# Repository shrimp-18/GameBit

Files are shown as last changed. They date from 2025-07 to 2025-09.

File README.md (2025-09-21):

# GameBit
GameBit is a custom project made for Hackclub. 
It is a portable Gaming Console (HAT) with a 2 inch LCD Screen, Audio Capabilities, 8 buttons for gameplay and 2 for on/off functionality, powered by a Raspberry Pi Zero 2W.
It is 130 X 44 mm in dimensions. 

I plan to put custom games in it :3
I made GameBit because I've always wanted to build a hardware project on my own and making a gaming console seemed cute. It was a very challenging project for a beginner, but I have learned a lot in the journey of making it. Game consoles are something that exist and I found a couple tutorials here and there but i still had to use a lot of my own brain to make it. But the experience I got from making this one will help me make a project I've been wanting to make since years and the tutorials for which do not exist.
3D View:


The Schematic:


The PCB:


The BOM:


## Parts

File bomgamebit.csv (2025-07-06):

Reference | Value | Datasheet | Footprint | Qty | DNP | Part
C1 | 0.1uF | https://lcsc.com/datasheet/lcsc_datasheet_2304140030_TORCH-CT41G-0805-2X1-50V-0-1-F-M-N_C138340.pdf | cap:C_0805 | 1 |  | 0.1uF Capacitor
C2 | 10uF | https://lcsc.com/datasheet/lcsc_datasheet_2304140030_Samsung-Electro-Mechanics-CL21A106KAYNNNE_C15850.pdf | cap:C_0805 | 1 |  | 10uF Capacitor
J1 | Conn_01x08_MountingPin | https://lcsc.com/product-detail/image/HB-PH3-25418PB2GOP_C6332201.html | mount:HB_PH3_25418PB2GOP_8Pin | 1 |  | Mounting pin 1x8
J3 | Conn_01x02 | https://lcsc.com/product-detail/image/PZ254V-11-02P_C492401.html | cap:PZ254V_11_02P | 1 |  | Mounting pin 1x2
LS1 | Speaker | https://jlcpcb.com/api/file/downloadByFileSystemAccessId/8590165296179802112 |  | 1 | DNP | Speaker 8ohm
SW1,SW2,SW3,SW4,SW5,SW6,SW7,SW8 | SW_Push | https://www.khon-switch.com/upload/1c/202404/TSW08131.pdf | button8:TSX08131_3.4x3.0_SMT | 8 |  | 8X8 tactile push button
SW9 | SW_SHDN | https://www.khon-switch.com/upload/1c/202404/TSW08131.pdf | on/off:TSX08131_3.4x3.0_SMT | 1 |  | 8X8 tactile push button
SW10 | JS102011SAQN | https://lcsc.com/datasheet/lcsc_datasheet_2410010333_C-K-JS102011SAQN_C221660.pdf | on/off:CK_JS102011SAQN | 1 |  | Slide button
U1 | SC1176 | https://datasheets.raspberrypi.com/rpizero2/raspberry-pi-zero-2-w-product-brief.pdf | rpi:MODULE_SC1176 | 1 |  | Raspberry Pi Zero 2W
U2 | MAX98357A | https://www.analog.com/media/en/technical-documentation/data-sheets/MAX98357A-MAX98357B.pdf | Package_DFN_QFN:TQFN-16-1EP_3x3mm_P0.5mm_EP1.23x1.23mm | 1 |  | Audio Module
LCD |  | https://files.waveshare.com/upload/a/ad/ST7789VW.pdf |  | 1 | DNP | LCD Display

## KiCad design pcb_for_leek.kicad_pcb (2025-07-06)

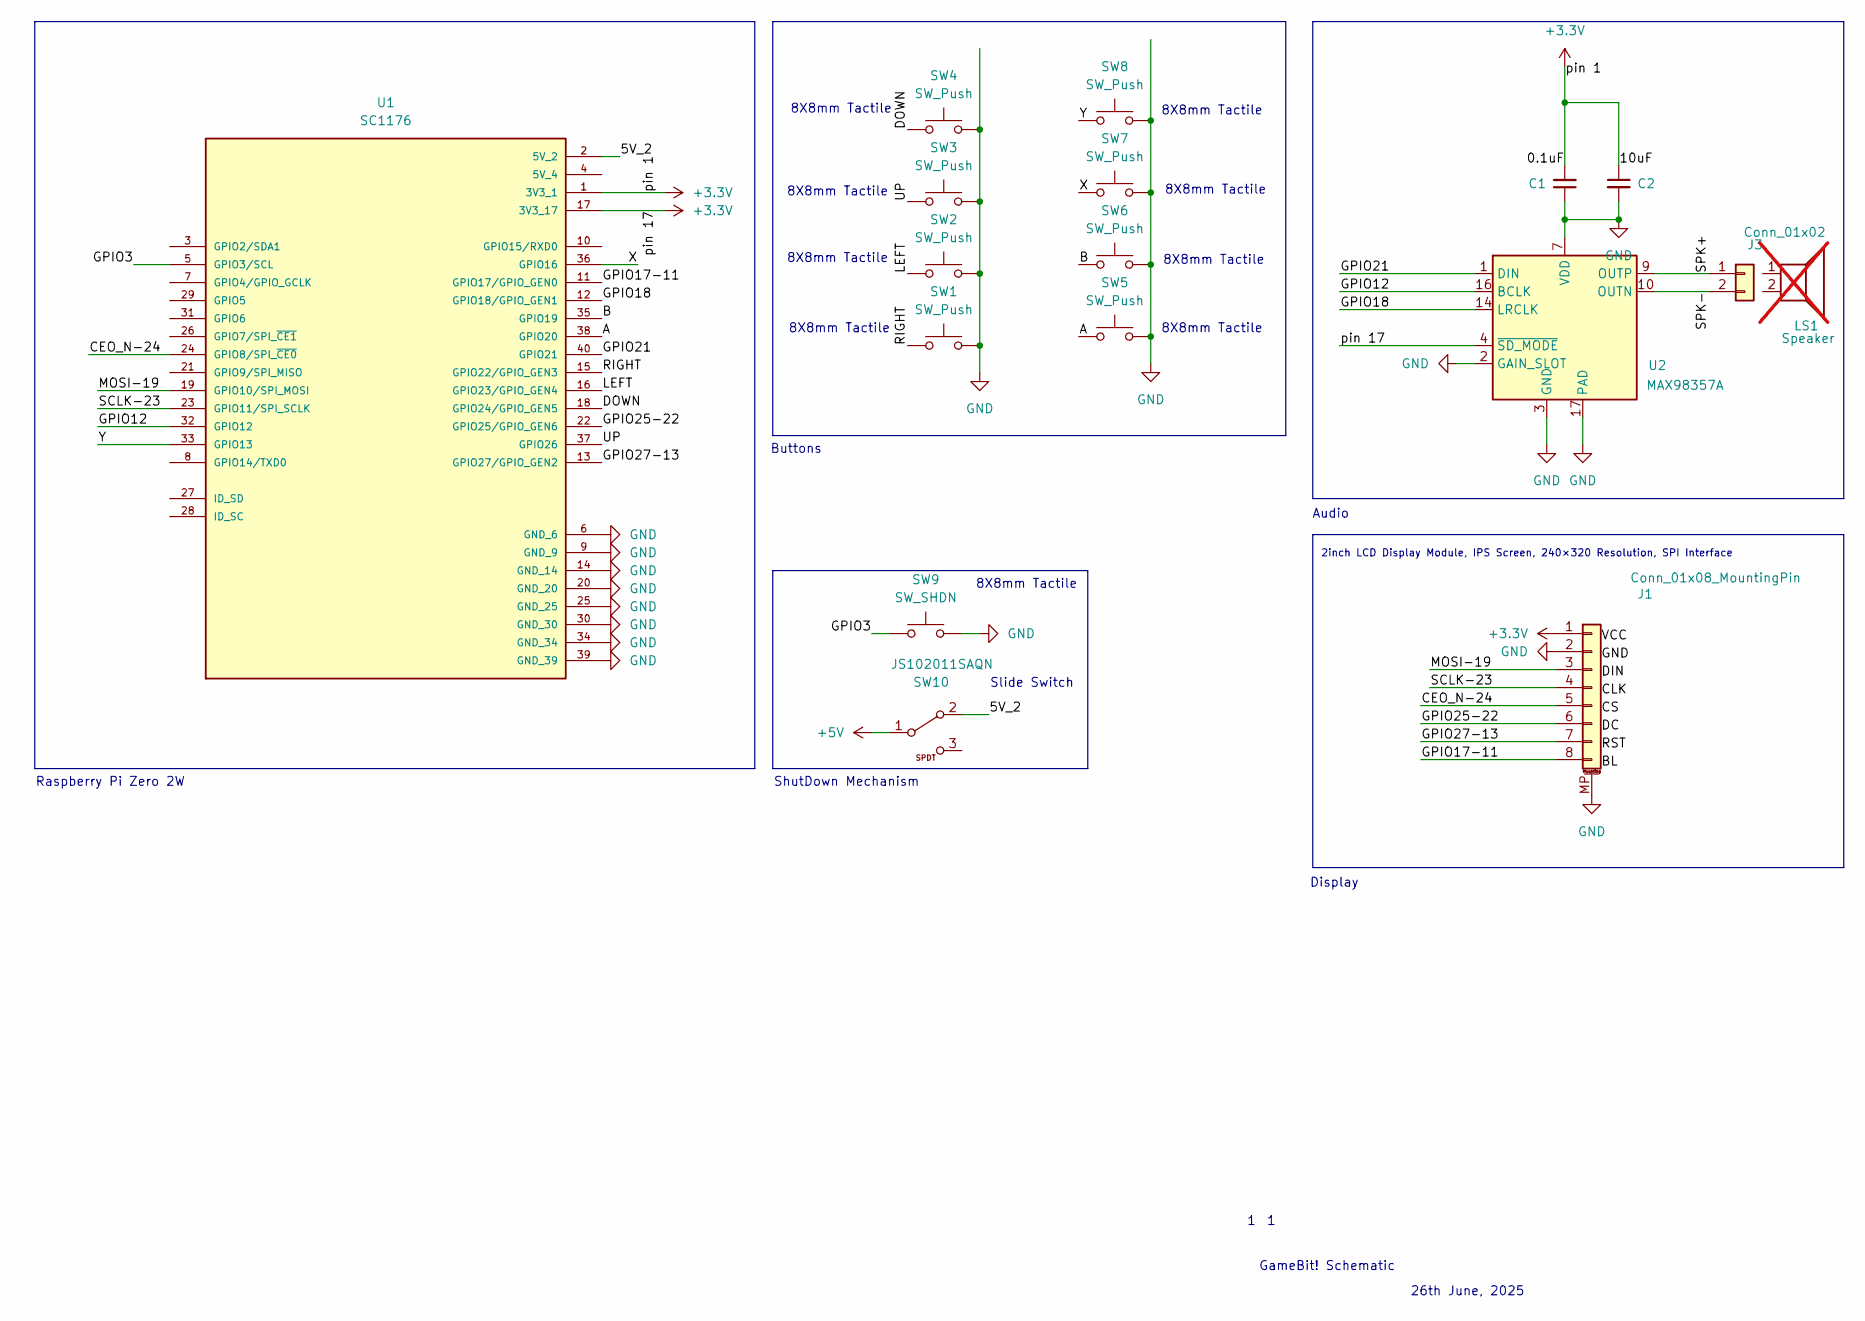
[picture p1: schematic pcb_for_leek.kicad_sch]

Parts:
C1: 0.1uF; C_0805
C2: 10uF; C_0805
J1: Conn_01x08_MountingPin; HB_PH3_25418PB2GOP_8Pin
J3: Conn_01x02; PZ254V_11_02P
LS1: Speaker; not fitted
SW1, SW2, SW3, SW4, SW5, SW6, SW7, SW8: SW_Push; TSX08131_3.4x3.0_SMT
SW9: SW_SHDN; TSX08131_3.4x3.0_SMT
SW10: JS102011SAQN; CK_JS102011SAQN; MPN JS102011SAQN; LCSC C221660
U1: SC1176; MODULE_SC1176; PARTREV April 2024; DigiKey_Part_Number 2648-SC1176-ND
U2: MAX98357A; TQFN-16-1EP_3x3mm_P0.5mm_EP1.23x1.23mm

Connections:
+3.3V: C1.2, C2.1, J1.1, U1.1 (3V3_1), U1.17 (3V3_17), U2.4 (~SD_MODE)
+5V: SW10.1 (COM)
/5V_2: SW10.2 (NO), U1.2 (5V_2)
/A: SW5.1, U1.38 (GPIO20)
/B: SW6.1, U1.35 (GPIO19)
/CEO_N-24: J1.5, U1.24 (GPIO8/SPI_~CE0)
/DOWN: SW4.1, U1.18 (GPIO24/GPIO_GEN5)
/GPIO3: SW9.1, U1.5 (GPIO3/SCL)
/GPIO12: U1.32 (GPIO12), U2.16 (BCLK)
/GPIO17-11: J1.8, U1.11 (GPIO17/GPIO_GEN0)
/GPIO18: U1.12 (GPIO18/GPIO_GEN1), U2.14 (LRCLK)
/GPIO21: U1.40 (GPIO21), U2.1 (DIN)
/GPIO25-22: J1.6, U1.22 (GPIO25/GPIO_GEN6)
/GPIO27-13: J1.7, U1.13 (GPIO27/GPIO_GEN2)
/LEFT: SW2.1, U1.16 (GPIO23/GPIO_GEN4)
/MOSI-19: J1.3, U1.19 (GPIO10/SPI_MOSI)
/RIGHT: SW1.1, U1.15 (GPIO22/GPIO_GEN3)
/SCLK-23: J1.4, U1.23 (GPIO11/SPI_SCLK)
/SPK+: J3.1 (SPK+), U2.9 (OUTP)
/SPK-: J3.2 (SPK-), U2.10 (OUTN)
/UP: SW3.1, U1.37 (GPIO26)
/X: SW7.1, U1.36 (GPIO16)
/Y: SW8.1, U1.33 (GPIO13)
GND: C1.1, C2.2, J1.2, J1.MP (MountPin), SW1.2, SW2.2, SW3.2, SW4.2, SW5.2, SW6.2, SW7.2, SW8.2, SW9.2, U1.6 (GND_6), U1.9 (GND_9), U1.14 (GND_14), U1.20 (GND_20), U1.25 (GND_25), U1.30 (GND_30), U1.34 (GND_34), U1.39 (GND_39), U2.2 (GAIN_SLOT), U2.3 (GND), U2.7 (VDD), U2.8 (VDD), U2.11 (GND), U2.15 (GND), U2.17 (PAD)

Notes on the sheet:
8X8mm Tactile
Audio
2inch LCD Display Module, IPS Screen, 240×320 Resolution, SPI Interface
GameBit! Schematic
26th June, 2025
Slide Switch
Raspberry Pi Zero 2W
Display
Buttons
ShutDown Mechanism

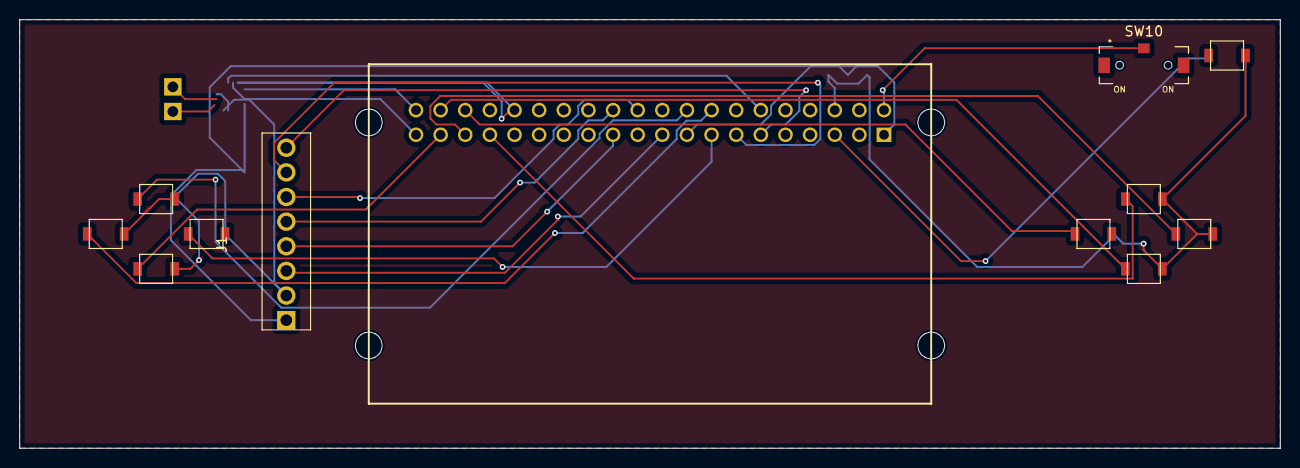
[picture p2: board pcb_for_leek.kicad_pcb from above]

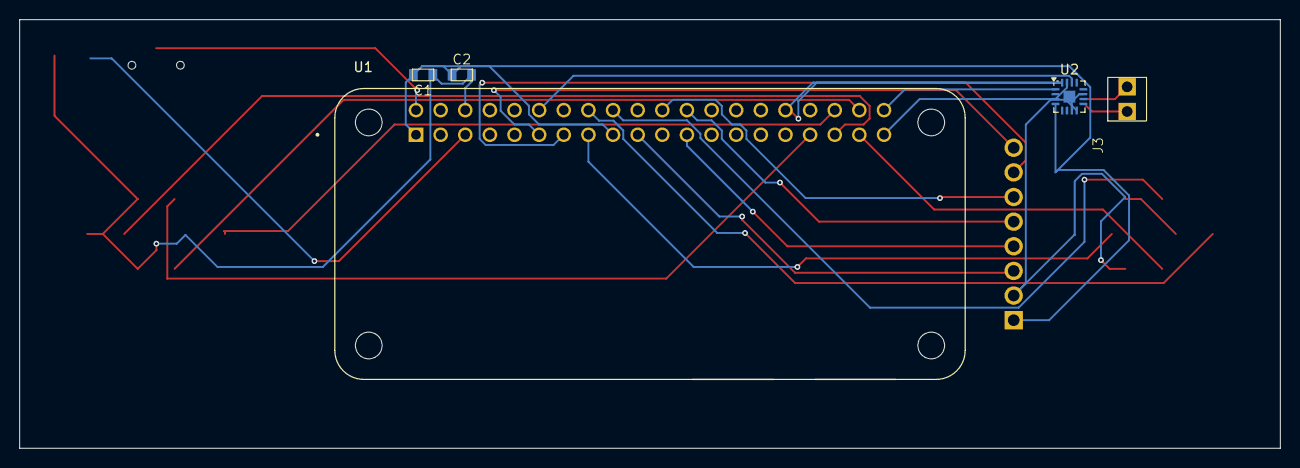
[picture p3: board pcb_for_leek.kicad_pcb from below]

Board: 2 copper layers, 130.0 x 44.2 mm, 16 parts (5 on the bottom side), 23 nets.

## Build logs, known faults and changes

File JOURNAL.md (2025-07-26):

---
Title: GameBit! Game Controller
Author: Neha A.
Description: A cuter and better GameBoy micro
Created_At: 24th June,2025
---
Total Time: 27 hours

(I didn't journal v actively as I was building this game console, so a lot of it is taken from my friend's DMs whom i regularly updated and my ChatGPT history)

10th May, 2025
The day I first started pondering the idea, I researched existing game consoles like the Hackapet, Sprig, and Pi-tin console etc.
Also saw a hell lot of yt tutorials on how game consoles are made, and also how to use kicad...bcs this is my second hardware project 
first was hackercard on easyeda.
Session: 3 hours (4pm to 7pm)

11th May, 2025
I decided to make something like the Game Boy Micro. Browsed a lot on LCSC, JLCPCB, and Waveshare on what hardware components to use.
For the mcu i settled on rpi 02W. Also found a good 2 inch lcd display on waveshare. Set up my kicad.
Session: 3 hours (8pm-11pm)

15th May,2025
In my schematic i made a system for the rpi to send data and power through a usb c cable which i thought would be useful (in the later stages i eventually remove it)
Also turns out that the connections i made were probably wrong.

Session : 2hours


25th May, 2025
By this time i realised by sending stuff on #electronics and smart hardware ppl that the usb c thingy wasnt really gonna work.So after more browsing and talking to chatgpt i settled on this chatgpt response. I figured I could just use the cable that the rpi  usually uses, and for portability I could use an <expensive> rechargable battery pack.
I also realised that the kicad symbol for the rpi i had been using all along were WRONG. So i found the correct symbol and footprint from a website and uploaded the files to my kicad preferences and did the assign footprint thingy (again all this took me long to figure out how to do bcs i havent used kicad before and i was learning how to use the software)

Session :2hours


26th May,2025
After a lot of searching for the footprint and symbol of the lcd screen i had chosen for my game console, i learned that we cant find every footprint and that i could just use a mounting pin instead. So i made connections for my screen from that 1X8 Mounting pin to rpi02w.

Session: 1hour


11th June,2025
Started figuring out a BOM.

Session: 1hour

13th June,2025
Went crazy searching for the perfect tactile push buttons on jlcpcb and lcsc. The perfect size(settled on 8x8mm using a wonderful reference image i found), the perfect datasheet(bcs everything is in CHINESE rahhh), the right amount of pins etc etc .



Session: 3 hours

14th June,2025
Connected buttons to rpi 


Session :30 mins
Made a pdf in canva regarding all the stuff i had completed on gamebit and some stuff which i planned to do which i will attach in my repo.
Session:30 mins
I found this repo which alexren linked on his game console guide: https://github.com/jackw01/pi-tin/ . The schematic is simply beautiful and helped me ALOT in the later stages on making this schematic. 

15th June,2025
Researched about audio modules and wanted to find smth better than MAX98357A but i ended up using the same. So added it to my schematic and connected it to rpi.
Session:2 hours


I was trying to find the perfect speaker for the next 2-3 days for mannyyy hours on jlc and lcsc. 


20th June,2025
I had decided on what speaker i was going to use so i added i made its footprint using the datasheet (one hell of a task).
I also made the footprint for the buttons i had chosen earlier. 
Session :2hours

25th June,2025
Searched more buttons to be used for on/off mechanism. I also learned how software+ power on/off worked so i used a tactile button of the software shut doen(bcs we dont wanna fully cut the power) and a slide button for power on/off bcs we wanna completely cut of the power.
Added this to my schematic. After all foorptints were assigned i made my pcb file :yay:

Also polished all the connections on my rpi and put a lot of GND labels.

Session: 2hours

26th June,2025
Started working on the pcb which was very easy compared to the schematic. Today i just eyeballed  stuff and arranged everything in a very rough format.

Session:30 mins

27th June,2025
Used correct measurements from datasheets to make the final pcb . Ran DRC.


Session:1hour

28th June,2025
Routed connections
Session:30 mins

and just like that the game console GameBit is finally completed. Will focus on making a 3d printed case on fusion360 later. 
ps: the hours are not inflated but im a newbie and researching stuff takes a lot of time 😭
Lmao its somehow came out to Total :24 hours 

25th July,2025

this happened while making the cad model +case
so i make the pcb from scratch AGAIN and while doing that i found like 2-3 more issues which i fixed.
Session:3 hours

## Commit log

2025-06-27 Added kicad files
    [pcb_for_leek.kicad_pcb, pcb_for_leek.kicad_sch]
2025-07-06 Added BOM
    [bomgamebit.csv]
2025-07-06 routed pcb
    [pcb_for_leek.kicad_pcb]
2025-07-26 changed the pcb bcs the design was kinda wrong
